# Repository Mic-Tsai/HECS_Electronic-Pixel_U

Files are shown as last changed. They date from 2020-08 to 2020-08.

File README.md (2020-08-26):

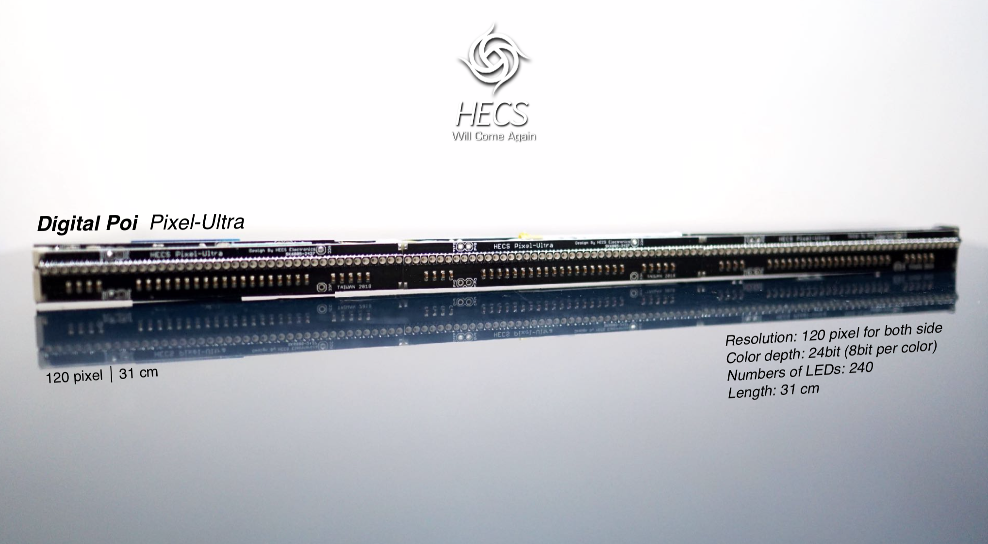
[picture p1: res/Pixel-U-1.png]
*HECS Electronic | Pixel-U*


## HECS Electronic | Pixel-U
### Light Painting Equipment



2013 | HECS

We are a visual team of POI arty performers. Design and develop the light-painting equipment which contains picture & dynamic presentation. This was my college side project during 2013-2014 in KUAS (National Kaohsiung University of Applied Sciences, Taiwan).

- [Promotional Video](https://youtu.be/c2NhDoxItCM)

2017 | Pixel-X

  Re-engineering hardware part, split the core as controller and display, purpose to minimum PCB after-assemble space. LEDs used the improved version SK6812B-3535 (package) from WS2812B-5050, got better heat radiating, the smaller dots will increase the image resolution.

**2018 | Pixel-U**

  **Base on Pixel-X prototype used the same controller board, rebuild the display layout up to 40 LEDs which is smaller package (SK6812B-2427). System compare detail please refer the following slide.**

```
Arduino tool kit, and require the following material:
- MCU: ATmega328p
- Storage: SD card
- Display: SK6812B-2427
- Power source: Li-Po Battery
```

##

### **About Mic**

Director of HECS, design light painting product that contains hardware layout and software programming.

- [Resume](https://drive.google.com/file/d/1NEWwNo3X4ogJMNzp6jpFyT0a6GPGhs7Q/view)

## 

### **About HECS**

Interesting how it works please refer for detail:

- [HECS ISSUU](https://issuu.com/56905554/docs/hecs_book)

- [HECS ISSUU moble device](https://issuu.com/56905554/docs/hecs-book_issuu)

- [HECS Electronics](https://drive.google.com/file/d/1tgr780FQ_Ib0JO3FdQn_M6LVbDeVmUmG/view?usp=sharing)

## 

### **About Hardware**

If you want to buy this board and are in Taiwan, please visit my shop: 

Will OPEN SOON:
* [HECS SHOP](https://www.)
* Contact me via mail (xbcke12345@gmail.com)
* If this project helping. Please generously support =)

   

## 
*HECS Electronic | Pixel-U*
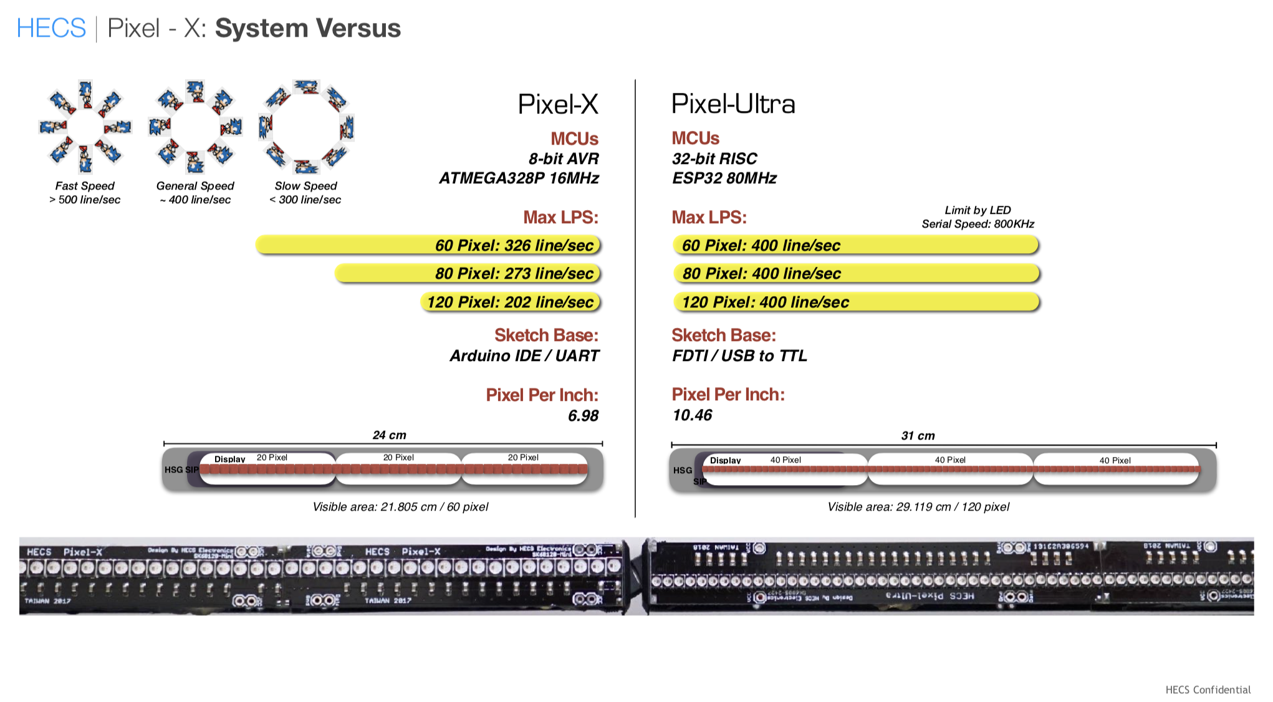
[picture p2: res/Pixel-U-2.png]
*HECS Electronic | Pixel-U*

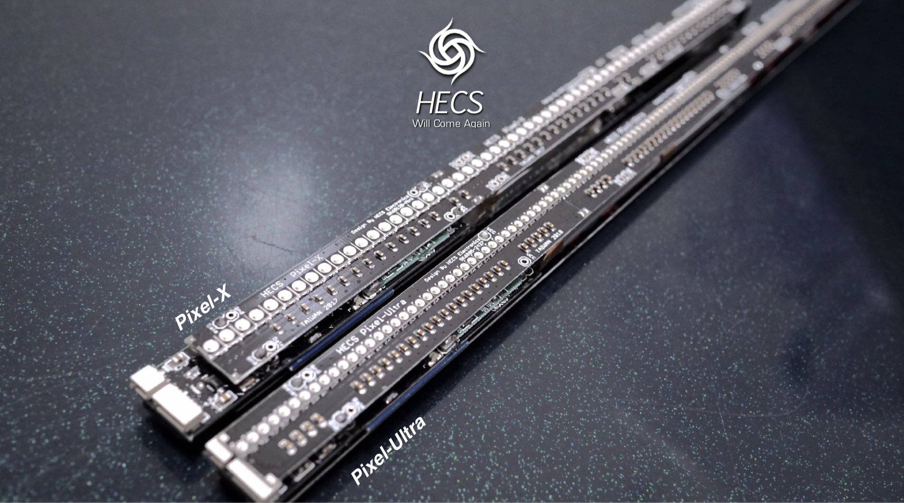
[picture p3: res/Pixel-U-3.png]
*HECS Electronic | Pixel-U*

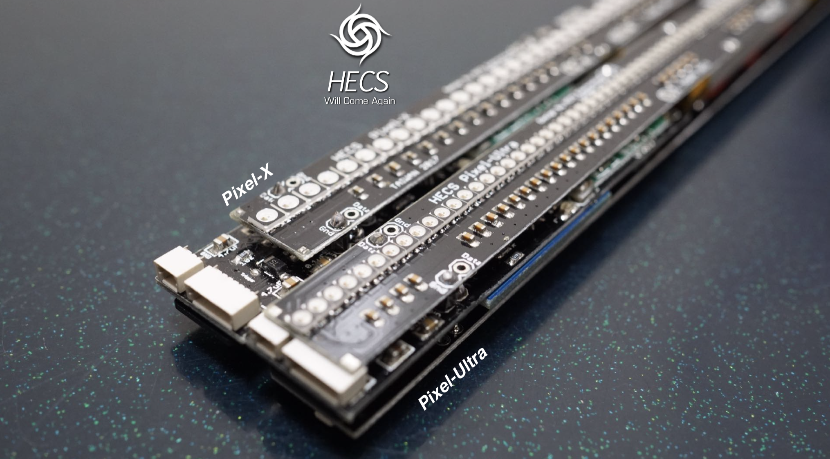
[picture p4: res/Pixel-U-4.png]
*HECS Electronic | Pixel-U*

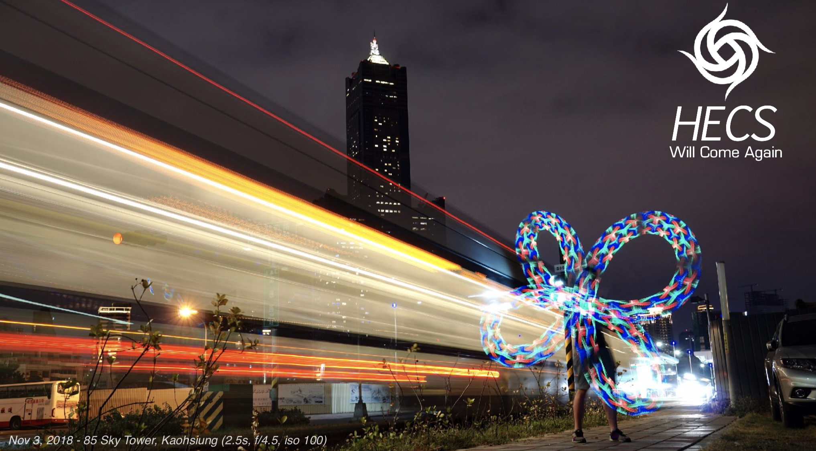
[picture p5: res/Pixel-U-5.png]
*HECS Electronic | Pixel-U*

*HECS Electronic | Pixel-U*
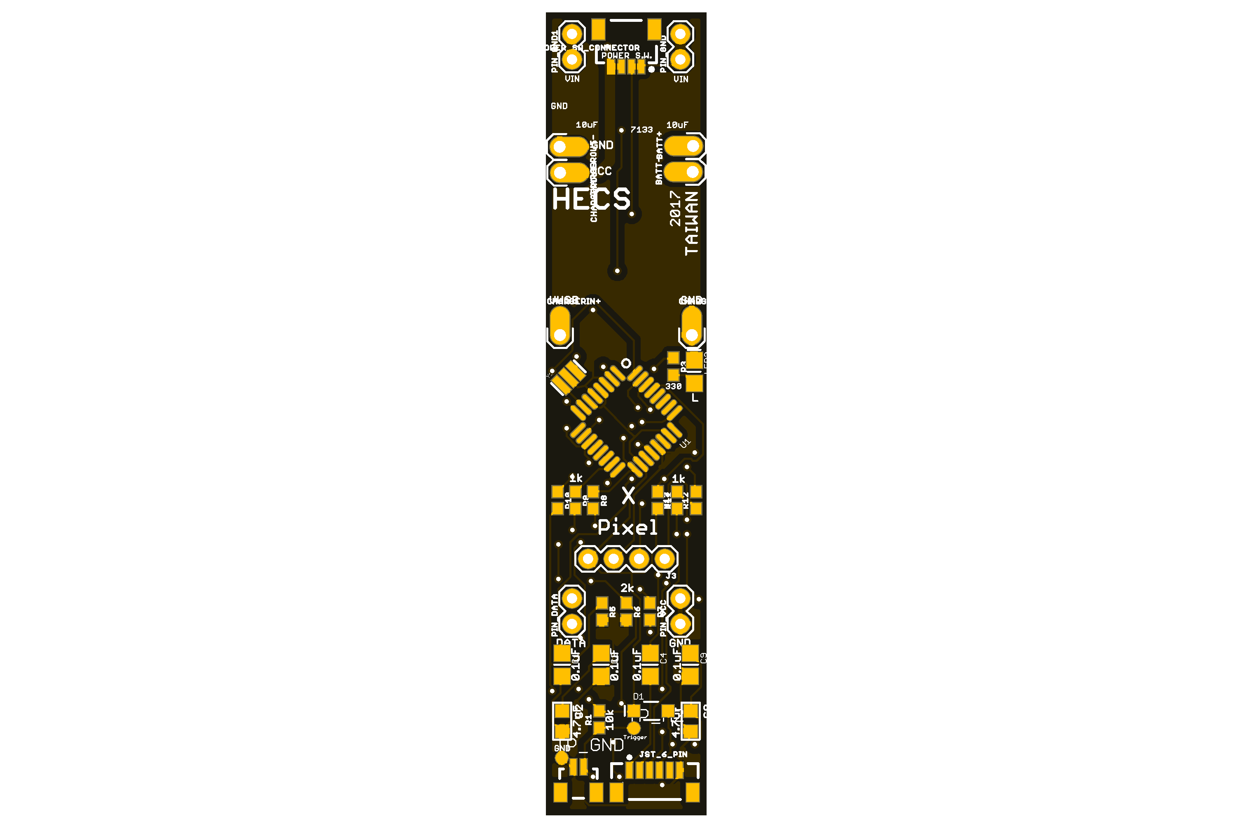
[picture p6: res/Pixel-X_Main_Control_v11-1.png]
*HECS Electronic | Pixel-U*

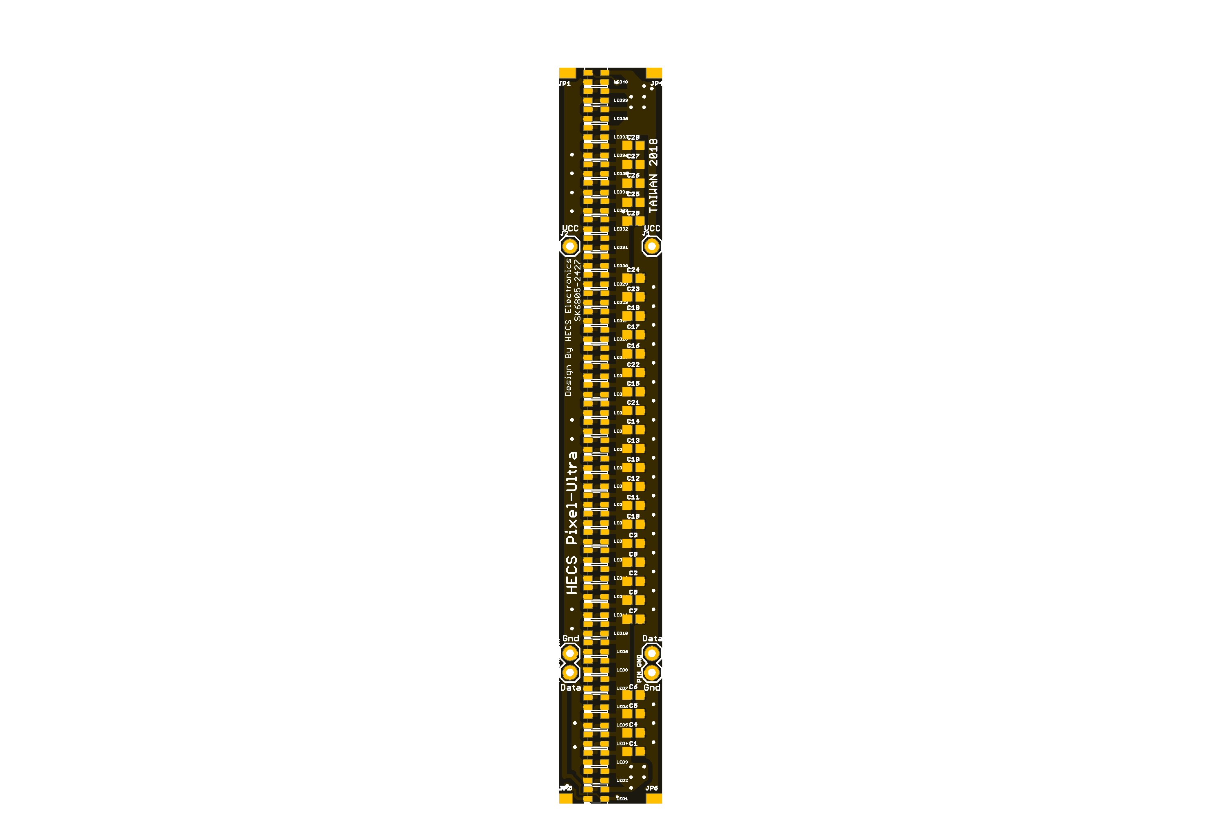
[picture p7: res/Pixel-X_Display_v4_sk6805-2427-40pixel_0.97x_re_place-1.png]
*HECS Electronic | Pixel-U*

## 

>### License Information
>>This product is open source! Both, our hardware and software are open source and licensed under the following:
>>#### Hardware
>>>All hardware is released under [Creative Commons Share-alike 4.0 International](http://creativecommons.org/licenses/by-sa/4.0/)
>>#### Software 
>>>All software is released under the MIT License [http://opensource.org/licenses/MIT](http://opensource.org/licenses/MIT)
>>#### Documentation
>>>The documentation on this page is released under [Creative Commons Share-alike 4.0 International](http://creativecommons.org/licenses/by-sa/4.0/)

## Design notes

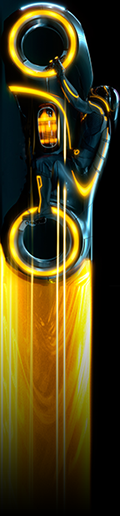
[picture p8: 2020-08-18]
Pixel-U_Image/Pixel-120/frame008.bmp

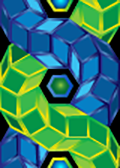
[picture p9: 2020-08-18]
Pixel-U_Image/Pixel-120/frame003.bmp

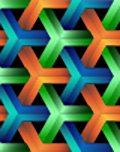
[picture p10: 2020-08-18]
Pixel-U_Image/Pixel-120/frame004.bmp

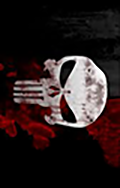
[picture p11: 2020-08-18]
Pixel-U_Image/Pixel-120/frame009.bmp

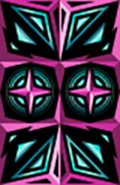
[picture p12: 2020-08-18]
Pixel-U_Image/Pixel-120/frame002.bmp

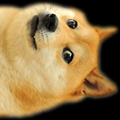
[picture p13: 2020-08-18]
Pixel-U_Image/Pixel-120/frame006.bmp

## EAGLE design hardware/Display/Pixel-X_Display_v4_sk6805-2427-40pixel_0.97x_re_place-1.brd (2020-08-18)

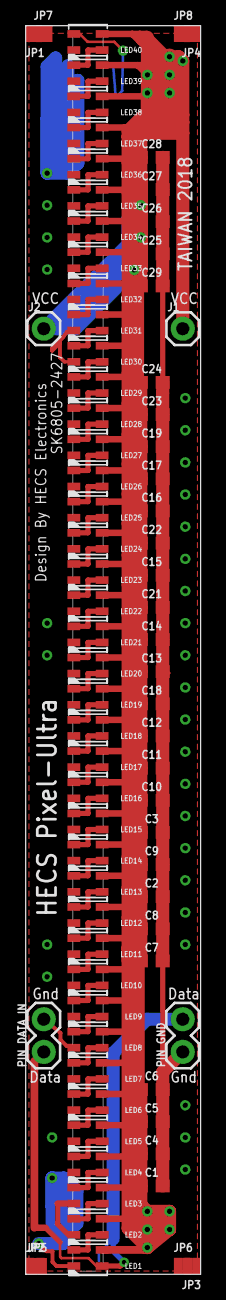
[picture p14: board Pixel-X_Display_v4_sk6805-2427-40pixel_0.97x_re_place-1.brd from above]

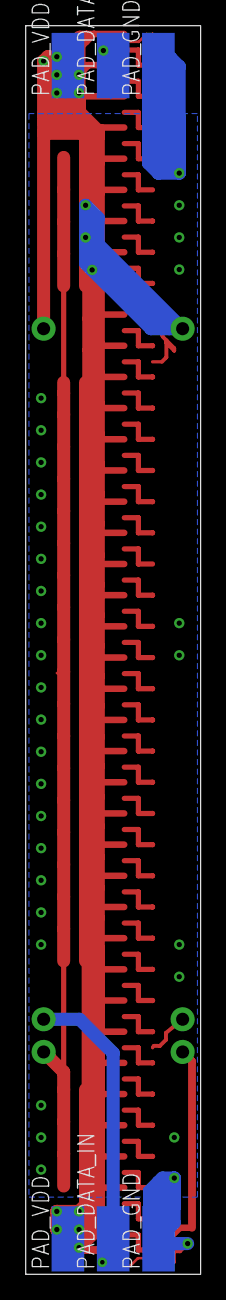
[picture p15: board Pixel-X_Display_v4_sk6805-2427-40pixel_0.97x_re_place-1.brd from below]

Board: 2 copper layers, 13.6 x 97.1 mm, 86 parts (6 on the bottom side), 43 nets.

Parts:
C1, C2, C3, C4, C5, C6, C7, C8, C9, C10, C11, C12, C13, C14, C15, C16, C17, C18, C19, C21, C22, C23, C24, C25, C26, C27, C28, C29: 0.1uF; 0603
J1, J2: 1X01
JP1, JP2, JP3, JP4, JP5, JP6, JP7, JP8: JUMPER-SMT_2_NO_NO-SILK; SMT-JUMPER_2_NO_NO-SILK
LED1, LED2, LED3, LED4, LED5, LED6, LED7, LED8, LED9, LED10, LED11, LED12, LED13, LED14, LED15, LED16, LED17, LED18, LED19, LED20, LED21, LED22, LED23, LED24, LED25, LED26, LED27, LED28, LED29, LED30, LED31, LED32, LED33, LED34, LED35, LED36, LED37, LED38, LED39, LED40: WS2812BSK68052427; LED3535
PAD_DATA_IN: SMD2,54-5,08
PAD_DATA_OUT: SMD2,54-5,08
PAD_GND, PAD_GND1: SMD2,54-5,08
PAD_VDD, PAD_VDD1: SMD2,54-5,08
PIN_DATA_IN: 1X02
PIN_GND: 1X02

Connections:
+5V: C1.1, C2.1, C3.1, C4.1, C5.1, C6.1, C7.1, C8.1, C9.1, C10.1, C11.1, C12.1, C13.1, C14.1, C15.1, C16.1, C17.1, C18.1, C19.1, C21.1, C22.1, C23.1, C24.1, C25.1, C26.1, C27.1, C28.1, C29.1, J1.1, J2.1, LED1.2, LED2.2, LED3.2, LED4.2, LED5.2, LED6.2, LED7.2, LED8.2, LED9.2, LED10.2, LED11.2, LED12.2, LED13.2, LED14.2, LED15.2, LED16.2, LED17.2, LED18.2, LED19.2, LED20.2, LED21.2, LED22.2, LED23.2, LED24.2, LED25.2, LED26.2, LED27.2, LED28.2, LED29.2, LED30.2, LED31.2, LED32.2, LED33.2, LED34.2, LED35.2, LED36.2, LED37.2, LED38.2, LED39.2, LED40.2, PAD_VDD.1, PAD_VDD1.1
COM: C1.2, C2.2, C3.2, C4.2, C5.2, C6.2, C7.2, C8.2, C9.2, C10.2, C11.2, C12.2, C13.2, C14.2, C15.2, C16.2, C17.2, C18.2, C19.2, C21.2, C22.2, C23.2, C24.2, C25.2, C26.2, C27.2, C28.2, C29.2, LED1.4, LED2.4, LED3.4, LED4.4, LED5.4, LED6.4, LED7.4, LED8.4, LED9.4, LED10.4, LED11.4, LED12.4, LED13.4, LED14.4, LED15.4, LED16.4, LED17.4, LED18.4, LED19.4, LED20.4, LED21.4, LED22.4, LED23.4, LED24.4, LED25.4, LED26.4, LED27.4, LED28.4, LED29.4, LED30.4, LED31.4, LED32.4, LED33.4, LED34.4, LED35.4, LED36.4, LED37.4, LED38.4, LED39.4, LED40.4, PAD_GND.1, PAD_GND1.1, PIN_DATA_IN.2, PIN_GND.1
unnamed: LED1.1, PAD_DATA_IN.1, PIN_DATA_IN.1, PIN_GND.2
unnamed: LED1.3, LED2.1
unnamed: LED2.3, LED3.1
unnamed: LED3.3, LED4.1
unnamed: LED4.3, LED5.1
unnamed: LED5.3, LED6.1
unnamed: LED29.3, LED30.1
unnamed: LED6.3, LED7.1
unnamed: LED7.3, LED8.1
unnamed: LED8.3, LED9.1
unnamed: LED9.3, LED10.1
unnamed: LED10.3, LED11.1
unnamed: LED11.3, LED12.1
unnamed: LED12.3, LED13.1
unnamed: LED13.3, LED14.1
unnamed: LED15.3, LED16.1
unnamed: LED16.3, LED17.1
unnamed: LED17.3, LED18.1
unnamed: LED18.3, LED19.1
unnamed: LED19.3, LED20.1
unnamed: LED14.3, LED15.1
unnamed: LED20.3, LED21.1
unnamed: LED21.3, LED22.1
unnamed: LED22.3, LED23.1
unnamed: LED23.3, LED24.1
unnamed: LED24.3, LED25.1
unnamed: LED25.3, LED26.1
unnamed: LED26.3, LED27.1
unnamed: LED27.3, LED28.1
unnamed: LED28.3, LED29.1
unnamed: LED30.3, LED31.1
unnamed: LED39.3, LED40.1
unnamed: LED38.3, LED39.1
unnamed: LED37.3, LED38.1
unnamed: LED36.3, LED37.1
unnamed: LED35.3, LED36.1
unnamed: LED34.3, LED35.1
unnamed: LED33.3, LED34.1
unnamed: LED32.3, LED33.1
unnamed: LED31.3, LED32.1
unnamed: LED40.3, PAD_DATA_OUT.1

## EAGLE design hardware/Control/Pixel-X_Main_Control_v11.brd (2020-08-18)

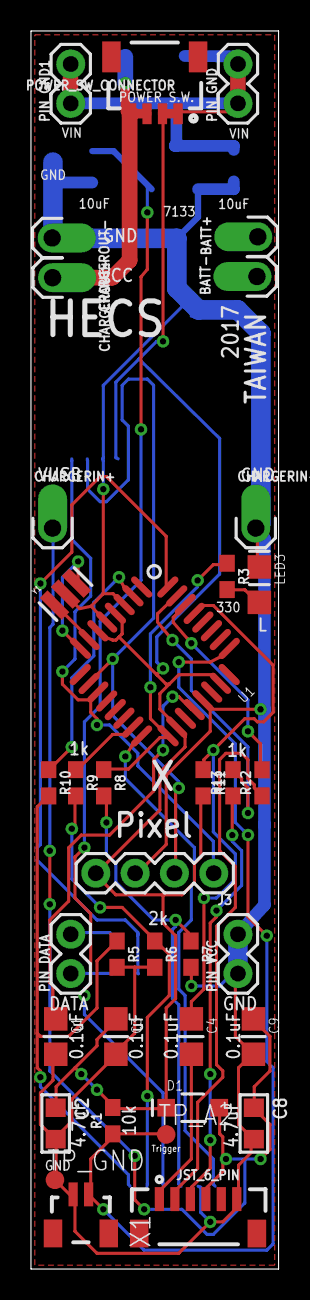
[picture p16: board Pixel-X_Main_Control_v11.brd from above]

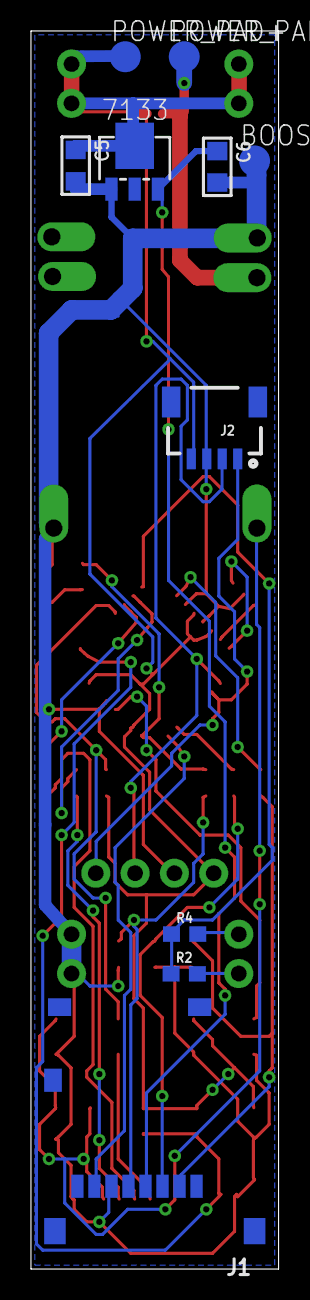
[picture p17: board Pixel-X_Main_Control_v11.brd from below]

Board: 2 copper layers, 16.0 x 80.0 mm, 47 parts (10 on the bottom side), 28 nets.

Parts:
7133: L78LXXCU/BU; SOT89
BATT+: 1X01_OFFSET
BATT-: 1X01_OFFSET
BOOSTOUT-: TPSQTP20R; TP20R
C1, C3, C4, C9: 0.1uF; CAP0805-NP
C2, C8: 4.7uF; C0805
C5, C6: 10uF; C0805
CHARGERIN+: 1X01_OFFSET
CHARGERIN-: 1X01_OFFSET
CHARGEROUT+: 1X01_OFFSET
CHARGEROUT-: 1X01_OFFSET
D1: MBR0520; SOD-123
J1: MICROSD_MOLEX_5025700893; 5025700893
J2: 1X04_1MM_RA
J3: 1X04
JST_6_PIN: JST_6_PIN_VERTICAL; JST-6-SMD-VERT-1.0MM
LED3: L_AMBER; LED0805
PIN_DATA: 1X02
PIN_GND, PIN_GND1: 1X02
PIN_VCC: 1X02
POWER_PAD+: TPSQTP20R; TP20R
POWER_PAD-: TPSQTP20R; TP20R
POWER_SW_CONNECTOR: 1X04_1MM_RA
R1: 10k; 0603
R2, R4: 120; 0603
R3: 330; 0603
R5, R6, R7: 2k; 0603
R8, R9, R10, R11, R12, R13: 1k; 0603
TP_A2: TPTP12R; TP12R
TP_GND: TPTP12R; TP12R
U1: ATMEGA328; QFP032
X1: BM02B-SRSS-TB
Y1: 16MHz; RESONATOR

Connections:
3V3OUT: 7133.3, C6.1, J1.P$4
+5V: 7133.4, C2.1, C3.1, C5.1, D1.1, J2.4, J3.4, PIN_GND.1, PIN_GND.2, PIN_GND1.1, PIN_GND1.2, POWER_PAD+.TP, POWER_SW_CONNECTOR.1, POWER_SW_CONNECTOR.2, R1.2, R11.2, U1.4, U1.6, U1.18, U1.23
A2: R1.1, TP_A2.TP, U1.25, X1.2
AREF: C1.1, U1.20
COM: 7133.1, BOOSTOUT-.TP, C1.2, C2.2, C3.2, C5.2, C6.2, C8.2, C9.2, CHARGERIN-.1, CHARGEROUT-.1, J1.P$6, J2.3, J3.3, JST_6_PIN.6, LED3.1, PIN_VCC.1, PIN_VCC.2, R5.2, R6.2, R7.2, TP_GND.TP, U1.3, U1.5, U1.21, X1.1, Y1.2
D0/RX: R12.2, U1.30
D1/TX: R13.2, U1.31
D2: R2.1, R4.1, U1.32
D4: R10.1, U1.2
D6: J2.2, J3.2, U1.10
D7: J2.1, J3.1, U1.11
D11/MOSI: R9.1, U1.15
D12/MISO: J1.P$7, U1.16
D13/SCK: R3.1, R8.1, U1.17
DTR: C4.1, R11.1, U1.29
unnamed: U1.8, Y1.3
unnamed: U1.7, Y1.1
unnamed: PIN_DATA.2, R4.2
unnamed: PIN_DATA.1, R2.2
unnamed: C4.2, JST_6_PIN.1
unnamed: LED3.2, R3.2
unnamed: J1.P$2, R5.1, R10.2
unnamed: J1.P$3, R6.1, R9.2
unnamed: J1.P$5, R7.1, R8.2
unnamed: CHARGEROUT+.1, POWER_PAD-.TP, POWER_SW_CONNECTOR.3, POWER_SW_CONNECTOR.4
RX: JST_6_PIN.2, R12.1
TX: JST_6_PIN.3, R13.1
VUSB: C8.1, C9.1, CHARGERIN+.1, D1.2, JST_6_PIN.4

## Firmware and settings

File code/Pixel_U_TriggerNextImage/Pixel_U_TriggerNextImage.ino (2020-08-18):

// ###################################################################################
// # Project: Pixel-X v8
// # Engineer:  Mic.Tsai
// # Date:  10 May 2018
// # Objective: Dev.board
// # Usage: ATmega328p
// ###################################################################################

/////////////////////////////////
// Important:
// Only Arduino 1.0.6 can sketch this code
// Check cycle time
/////////////////////////////////

// Requires SdFat library for Arduino:
// http://code.google.com/p/sdfatlib/

// Requires NeoPixel library:
// https://github.com/adafruit/Adafruit_NeoPixel

// This project is base on NeoPixel Painter from Adafruit 
// If you need detail building process please visit here (step by step)
// https://learn.adafruit.com/neopixel-painter?view=all
// https://github.com/adafruit/NeoPixel_Painter
// ###################################################################################

#include <SdFat.h>
#include <avr/pgmspace.h>
#include "./gamma.h"

// CONFIGURABLE STUFF --------------------------------------------------------

#define N_LEDS       120 // Max value is 170 (fits one SD card block)
#define CARD_SELECT   4 // SD card select pin (some shields use #4, not 10)
#define LED_PIN        2 // NeoPixels connect here
#define SPEED         A0 // Speed-setting dial
#define BRIGHTNESS    A0 // Brightness-setting dial
#define TRIGGER       A2 // Playback trigger pin
#define CURRENT_MAX 500 // Max current from power supply (mA)

////1600 for 60 pixel
////3200 for 120 pixel

#define OVERHEAD 150 // Extra microseconds for loop processing, etc.

uint8_t           sdBuf[512],  // One SD block (also for NeoPixel color data)
                  pinMask;     // NeoPixel pin bitmask
uint16_t          maxLPS,      // Max playback lines/sec
                  nFrames = 0, // Total # of image files
                  frame   = 0; // Current image # being painted
uint32_t          firstBlock,  // First block # in temp working file
                  nBlocks;     // Number of blocks in file
Sd2Card           card;        // SD card global instance (only one)
SdVolume          volume;      // Filesystem global instance (only one)
SdFile            root;        // Root directory (only one)
volatile uint8_t *port;        // NeoPixel PORT register

//Forward Declaration: make 1.6.7+ happy
boolean bmpProcess(SdFile &path, char *inName, char *outName, uint8_t *brightness);

// INITIALIZATION ------------------------------------------------------------

void setup() {
  uint8_t  b, startupTrigger, minBrightness;
  char     infile[13], outfile[13];
  boolean  found;
  uint16_t i, n;
  SdFile   tmp;
  uint32_t lastBlock;


  digitalWrite(TRIGGER, HIGH);           // Enable pullup on trigger button
  startupTrigger = digitalRead(TRIGGER); // Poll startup trigger ASAP
  Serial.begin(57600);
  pinMode(LED_PIN, OUTPUT);              // Enable NeoPixel output
  digitalWrite(LED_PIN, LOW);            // Default logic state = low
  port    = portOutputRegister(digitalPinToPort(LED_PIN));
  pinMask = digitalPinToBitMask(LED_PIN);
  memset(sdBuf, 0, N_LEDS * 3);          // Clear LED buffer
  show();                                // Init LEDs to 'off' state
#ifdef ENCODERSTEPS
  digitalWrite(5, HIGH);                 // Enable pullup on encoder pin
#endif

  Serial.print(F("Initializing SD card..."));
  if(!card.init(SPI_FULL_SPEED, CARD_SELECT)) {
    error(F("failed. Things to check:\n"
            "* is a card is inserted?\n"
            "* Is your wiring correct?\n"
            "* did you edit CARD_SELECT to match the SD shield or module?"));
  }
  Serial.println(F("OK"));

  if(!volume.init(&card)) {
    error(F("Could not find FAT16/FAT32 partition.\n"
            "Make sure the card is formatted."));
  }
  root.openRoot(&volume);

  // This simple application always reads the files 'frameNNN.bmp' in
  // the root directory; there's no file selection mechanism or UI.

  // If button is held at startup, the processing step is skipped, just
  // goes right to playback of the prior converted file(s) (if present).
  if(startupTrigger == LOW) { // No button press

    // Two passes are made over the input images.  First pass counts the
    // files and estimates the max brightness level that the power supply
    // can sustain...
    minBrightness = 255;
    do {
      sprintf(infile, "frame%03d.bmp", nFrames);
      b = 255; // Assume frame at full brightness to start...
      // ...it's then modified by the bmpProcess() function here to the
      // actual brightness limit the UBEC can sustain for *this image*.
      if(found = bmpProcess(root, infile, NULL, &b)) {
        nFrames++;
        // Keep track of the minimum 'b' value returned for *all images*.
        // This will later be applied to all, in order that multi-frame
        // animations can have consistent brightness throughout.
        if(b < minBrightness) minBrightness = b;
      }
    } while(found && (nFrames < 1000));

    Serial.print(nFrames);
    Serial.print(" frames\nbrightness = ");
    Serial.println(minBrightness);

    // Read dial, setting brightness between 1 (almost but not quite off)
    // and the previously-estimated safe max.
    minBrightness = map(analogRead(BRIGHTNESS), 0, 1023, 1, minBrightness);
  
    // Second pass now applies brightness adjustment while converting
    // the image(s) from BMP to a raw representation of NeoPixel data
    // (this outputs the file(s) 'frameNNN.tmp' -- any existing file
    // by that name will simply be clobbered, IT DOES NOT ASK).
    for(i=0; i<nFrames; i++) {
      sprintf(infile , "frame%03d.bmp", i);
      sprintf(outfile, "frame%03d.tmp", i);
      b = minBrightness; // Reset b to safe limit on each loop iteration
      bmpProcess(root, infile, outfile, &b);
    }
    //while(digitalRead(TRIGGER) == HIGH); // Wait for button release

  } else { // Button held -- use existing data

    do { // Scan for files to get nFrames
      sprintf(infile, "frame%03d.tmp", nFrames);
      if(found = tmp.open(&root, infile, O_RDONLY)) {
        if(tmp.contiguousRange(&firstBlock, &lastBlock)) {
          nFrames++;
        }
        tmp.close();
      }
    } while(found);

  } // end startupTrigger test

#ifdef ENCODERSTEPS
  // To use a rotary encoder rather than timer, connect one output
  // of encoder to T1 pin (digital pin 5 on Arduino Uno).  A small
  // capacitor across the encoder pins may help for debouncing.
  TCCR1A = _BV(WGM11) | _BV(WGM10);
  TCCR1B = _BV(WGM13) | _BV(WGM12) | _BV(CS12) | _BV(CS11);
#else
  // Prepare for playback from file; make a full read pass through the
  // file to estimate block read time (+5% margin) and max playback
  // lines/sec.  Not all SD cards perform the same.  This makes sure a
  // reasonable speed limit is used.
  for(i=0; i<nFrames; i++) { // Scan all files
    sprintf(infile, "frame%03d.tmp", i);
    tmp.open(&root, infile, O_RDONLY);
    tmp.contiguousRange(&firstBlock, &lastBlock);
    nBlocks = tmp.fileSize() / 512;
    tmp.close();
    n = (uint16_t)(1000000L /                         // 1 uSec /
      (((benchmark(firstBlock, nBlocks) * 21) / 20) + // time + 5% +
       (N_LEDS * 30L) + OVERHEAD));                   // 30 uSec/pixel
    if(n > maxLPS) maxLPS = n;
  }
  if(maxLPS > 400) maxLPS = 400; // NeoPixel PWM rate is ~400 Hz
  Serial.print(F("Max lines/sec: "));
  Serial.println(maxLPS);

  // Set up Timer1 for 64:1 prescale (250 KHz clock source),
  // fast PWM mode, no PWM out.
  TCCR1A = _BV(WGM11) | _BV(WGM10);
  TCCR1B = _BV(WGM13) | _BV(WGM12) | _BV(CS11) | _BV(CS10);
  // Timer1 interrupt is not used; instead, overflow bit is tightly
  // polled.  Very infrequently a block read may inexplicably take longer
  // than normal...using an interrupt, the code would clobber itself.
  // By polling instead, worst case is just a minor glitch where the
  // corresponding row will be a little thicker than normal.
#endif

  // Timer0 interrupt is disabled for smoother playback.
  // This means delay(), millis(), etc. won't work after this.
  TIMSK0 = 0;
}

// Startup error handler; doesn't return, doesn't run loop(), just stops.
static void error(const __FlashStringHelper *ptr) {
    Serial.println(ptr); // Show message
    for(;;);             // and hang
}

// PLAYBACK LOOP -------------------------------------------------------------

void loop() {
  uint32_t block    = 0;     // Current block # within file
  boolean  stopFlag = false; // If set, stop playback loop
  uint32_t lastBlock;
  char     infile[13];
  SdFile   tmp;

  // Get existing contiguous tempfile info
  sprintf(infile, "frame%03d.tmp", frame);
  if(!tmp.open(&root, infile, O_RDONLY)) {
    error(F("Could not open NeoPixel tempfile for input"));
  }
  if(!tmp.contiguousRange(&firstBlock, &lastBlock)) {
    error(F("NeoPixel tempfile is not contiguous"));
  }
  // Number of blocks needs to be calculated from file size, not the
  // range values.  The contiguous file creation and range functions
  // work on cluster boundaries, not necessarily the actual file size.
  nBlocks = tmp.fileSize() / 512;

  tmp.close(); // File handle is no longer accessed, just block reads

  // Stage first block, but don't display yet -- the loop below
  // does that only when Timer1 overflows.
  card.readBlock(firstBlock, sdBuf);
  // readBlock is used rather than readStart/readData/readEnd as
  // the duration between block reads may exceed the SD timeout.

  while(digitalRead(TRIGGER) == LOW);   // Wait for trigger button

#ifdef ENCODERSTEPS
  // Set up for rotary encoder
  TCNT1 = 0;
  OCR1A = ENCODERSTEPS;
#else
  // Set up timer based on dial input
  uint32_t linesPerSec = map(analogRead(SPEED), 0, 1023, 10, maxLPS);
  // Serial.println(linesPerSec);
  OCR1A = (F_CPU / 64) / linesPerSec;          // Timer1 interval
#endif

  for(;;) {
    while(!(TIFR1 & _BV(TOV1)));               // Wait for Timer1 overflow
    TIFR1 |= _BV(TOV1);                        // Clear overflow bit

    show();                                    // Display current line
    if(stopFlag) break;                        // Break when done

    if(++block >= nBlocks) {                   // Past last block?
      if(digitalRead(TRIGGER) == LOW) {       // Trigger released?
        memset(sdBuf, 0, N_LEDS * 3);          // LEDs off on next pass
        stopFlag = true;                       // Stop playback on next pass
        continue;
      }                                        // Else trigger still held
      block = 0;                               // Loop back to start
    }
    card.readBlock(block + firstBlock, sdBuf); // Load next pixel row
  }

  if(++frame >= nFrames) frame = 0;
}

// BMP->NEOPIXEL FILE CONVERSION ---------------------------------------------

#define BMP_BLUE  0 // BMP and NeoPixels have R/G/B color
#define BMP_GREEN 1 // components in different orders.
#define BMP_RED   2 // (BMP = BGR, Neo = GRB)
#define NEO_GREEN 0
#define NEO_RED   1
#define NEO_BLUE  2

// Convert file from 24-bit Windows BMP format to raw NeoPixel datastream.
// Conversion is bottom-to-top (see notes below)...for horizontal light
// painting, the image is NOT rotated here (the per-pixel file seeking this
// requires takes FOREVER on the Arduino).  Instead, such images should be
// rotated counterclockwise (in Photoshop or other editor) prior to moving
// to SD card.  As currently written, both the input and output files need
// to be in the same directory.  Brightness is set during conversion; there
// aren't enough cycles to do this in realtime during playback.  To change
// brightness, re-process image file using new brightness value.
boolean bmpProcess(
  SdFile  &path,
  char    *inName,
  char    *outName,
  uint8_t *brightness) {

  SdFile    inFile,              // Windows BMP file for input
            outFile;             // NeoPixel temp file for output
  boolean   ok        = false,   // 'true' on valid BMP & output file
            flip      = false;   // 'true' if image stored top-to-bottom
  int       bmpWidth,            // BMP width in pixels
            bmpHeight,           // BMP height in pixels
            bmpStartCol,         // First BMP column to process (crop/center)
            columns,             // Number of columns to process (crop/center)
            row,                 // Current image row (Y)
            column;              // and column (X)
  uint8_t  *ditherRow,           // 16-element dither array for current row
            pixel[3],            // For reordering color data, BGR to GRB
            b = 0,               // 1 + *brightness
            d,                   // Dither value for row/column
            color,               // Color component index (R/G/B)
            raw,                 // 'Raw' R/G/B color value
            corr,                // Gamma-corrected R/G/B
           *ledPtr,              // Pointer into sdBuf (output)
           *ledStartPtr;         // First LED column to process (crop/center)
  uint16_t  b16;                 // 16-bit dup of b
  uint32_t  bmpImageoffset,      // Start of image data in BMP file
            lineMax   = 0L,      // Cumulative brightness of brightest line
            rowSize,             // BMP row size (bytes) w/32-bit alignment
            sum,                 // Sum of pixels in row
            startTime = millis();

  if(brightness)           b = 1 + *brightness; // Wraps around, fun with maths
  else if(NULL == outName) return false; // MUST pass brightness for power est.

  Serial.print(F("Reading file '"));
  Serial.print(inName);
  Serial.print(F("'..."));
  if(!inFile.open(&path, inName, O_RDONLY)) {
    Serial.println(F("error"));
    return false;
  }

  if(inFile.read(sdBuf, 34)             &&    // Load header
    (*(uint16_t *)&sdBuf[ 0] == 0x4D42) &&    // BMP signature
    (*(uint16_t *)&sdBuf[26] == 1)      &&    // Planes: must be 1
    (*(uint16_t *)&sdBuf[28] == 24)     &&    // Bits per pixel: must be 24
    (*(uint32_t *)&sdBuf[30] == 0)) {         // Compression: must be 0 (none)
    // Supported BMP format -- proceed!
    bmpImageoffset = *(uint32_t *)&sdBuf[10]; // Start of image data
    bmpWidth       = *(uint32_t *)&sdBuf[18]; // Image dimensions
    bmpHeight      = *(uint32_t *)&sdBuf[22];
    // That's some nonportable, endian-dependent code right there.

    Serial.print(bmpWidth);
    Serial.write('x');
    Serial.print(bmpHeight);
    Serial.println(F(" pixels"));

    if(outName) { // Doing conversion?  Need outFile.
      // Delete existing outFile file (if any)
      (void)SdFile::remove(&path, outName);
      Serial.print(F("Creating contiguous file..."));
      // NeoPixel working file is always 512 bytes (one SD block) per row
      if(outFile.createContiguous(&path, outName, 512L * bmpHeight)) {
        uint32_t lastBlock;
        outFile.contiguousRange(&firstBlock, &lastBlock);
        // Once we have the first block index, the file handle
        // is no longer needed -- raw block writes are used.
        outFile.close();
        nBlocks = bmpHeight; // See note in setup() re: block calcs
        ok      = true;      // outFile is good; proceed
        Serial.println(F("OK"));
      } else {
        Serial.println(F("error"));
      }
    } else ok = true; // outFile not needed; proceed

    if(ok) { // Valid BMP and contig file (if needed) are ready
      Serial.print(F("Processing..."));

      rowSize = ((bmpWidth * 3) + 3) & ~3; // 32-bit line boundary
      b16     = (int)b;

      if(bmpHeight < 0) {       // If bmpHeight is negative,
        bmpHeight = -bmpHeight; // image is in top-down order.
        flip      = true;       // Rare, but happens.
      }

      if(bmpWidth >= N_LEDS) { // BMP matches LED bar width, or crop image
        bmpStartCol = (bmpWidth - N_LEDS) / 2;
        ledStartPtr = sdBuf;
        columns     = N_LEDS;
      } else {                 // Center narrow image within LED bar
        bmpStartCol = 0;
        ledStartPtr = &sdBuf[((N_LEDS - bmpWidth) / 2) * 3];
        columns     = bmpWidth;
        memset(sdBuf, 0, N_LEDS * 3); // Clear left/right pixels
      }

      for(row=0; row<bmpHeight; row++) { // For each row in image...
        Serial.write('.');
        // Image is converted from bottom to top.  This is on purpose!
        // The ground (physical ground, not the electrical kind) provides
        // a uniform point of reference for multi-frame vertical painting...
        // could then use something like a leaf switch to trigger playback,
        // lifting the light bar like making giant soap bubbles.

        // Seek to first pixel to load for this row...
        inFile.seekSet(
          bmpImageoffset + (bmpStartCol * 3) + (rowSize * (flip ?
          (bmpHeight - 1 - row) : // Image is stored top-to-bottom
          row)));                 // Image stored bottom-to-top
        if(!inFile.read(ledStartPtr, columns * 3))  // Load row
          Serial.println(F("Read error"));

        sum       = 0L;
        ditherRow = (uint8_t *)&dither[row & 0x0F]; // Dither values for row
        ledPtr    = ledStartPtr;
        for(column=0; column<columns; column++) {   // For each column...
          if(b) { // Scale brightness, reorder R/G/B
            pixel[NEO_BLUE]  = (ledPtr[BMP_BLUE]  * b16) >> 8;
            pixel[NEO_GREEN] = (ledPtr[BMP_GREEN] * b16) >> 8;
            pixel[NEO_RED]   = (ledPtr[BMP_RED]   * b16) >> 8;
          } else { // Full brightness, reorder R/G/B
            pixel[NEO_BLUE]  = ledPtr[BMP_BLUE];
            pixel[NEO_GREEN] = ledPtr[BMP_GREEN];
            pixel[NEO_RED]   = ledPtr[BMP_RED];
          }

          d = pgm_read_byte(&ditherRow[column & 0x0F]); // Dither probability
          for(color=0; color<3; color++) {              // 3 color bytes...
            raw  = pixel[color];                        // 'Raw' G/R/B
            corr = pgm_read_byte(&gamma[raw]);          // Gamma-corrected
            if(pgm_read_byte(&bump[raw]) > d) corr++;   // Dither up?
            *ledPtr++ = corr;                           // Store back in sdBuf
            sum      += corr;                           // Total brightness
          } // Next color byte
        } // Next column

        if(outName) {
          if(!card.writeBlock(firstBlock + row, (uint8_t *)sdBuf))
            Serial.println(F("Write error"));
        }
        if(sum > lineMax) lineMax = sum;

      } // Next row
      Serial.println(F("OK"));

      if(brightness) {
        lineMax = (lineMax * 20) / 255; // Est current @ ~20 mA/LED
        if(lineMax > CURRENT_MAX) {
          // Estimate suitable brightness based on CURRENT_MAX
          *brightness = (*brightness * (uint32_t)CURRENT_MAX) / lineMax;
        } // Else no recommended change
      }

      Serial.print(F("Processed in "));
      Serial.print(millis() - startTime);
      Serial.println(F(" ms"));

    } // end 'ok' check
  } else { // end BMP header check
    Serial.println(F("BMP format not recognized."));
  }

  inFile.close();
  return ok; // 'false' on various file open/create errors
}

// MISC UTILITY FUNCTIONS ----------------------------------------------------

// Estimate maximum block-read time for card (microseconds)
static uint32_t benchmark(uint32_t block, uint32_t n) {
  uint32_t t, maxTime = 0L;

  do {
    t = micros();
    card.readBlock(block++, sdBuf);
    if((t = (micros() - t)) > maxTime) maxTime = t;
  } while(--n);

  return maxTime;
}

// NEOPIXEL FUNCTIONS --------------------------------------------------------

// The normal NeoPixel library isn't used by this project.  SD I/O and
// NeoPixels need to occupy the same buffer, there isn't quite an elegant
// way to do this with the existing library that avoids refreshing a longer
// strip than necessary.  Instead, just the core update function for 800 KHz
// pixels on 16 MHz AVR is replicated here; not handling every permutation.

static void show(void) {
  volatile uint16_t
    i   = N_LEDS * 3; // Loop counter
  volatile uint8_t
   *ptr = sdBuf,      // Pointer to next byte
    b   = *ptr++,     // Current byte value
    hi,               // PORT w/output bit set high
    lo,               // PORT w/output bit set low
    next,
    bit = 8;

  noInterrupts();
  hi   = *port |  pinMask;
  lo   = *port & ~pinMask;
  next = lo;

  asm volatile(
   "head20_%=:"                "\n\t"
    "st   %a[port],  %[hi]"    "\n\t"
    "sbrc %[byte],  7"         "\n\t"
     "mov  %[next], %[hi]"     "\n\t"
    "dec  %[bit]"              "\n\t"
    "st   %a[port],  %[next]"  "\n\t"
    "mov  %[next] ,  %[lo]"    "\n\t"
    "breq nextbyte20_%="       "\n\t"
    "rol  %[byte]"             "\n\t"
    "rjmp .+0"                 "\n\t"
    "nop"                      "\n\t"
    "st   %a[port],  %[lo]"    "\n\t"
    "nop"                      "\n\t"
    "rjmp .+0"                 "\n\t"
    "rjmp head20_%="           "\n\t"
   "nextbyte20_%=:"            "\n\t"
    "ldi  %[bit]  ,  8"        "\n\t"
    "ld   %[byte] ,  %a[ptr]+" "\n\t"
    "st   %a[port], %[lo]"     "\n\t"
    "nop"                      "\n\t"
    "sbiw %[count], 1"         "\n\t"
     "brne head20_%="          "\n"
    : [port]  "+e" (port),
      [byte]  "+r" (b),
      [bit]   "+r" (bit),
      [next]  "+r" (next),
      [count] "+w" (i)
    : [ptr]    "e" (ptr),
      [hi]     "r" (hi),
      [lo]     "r" (lo));

  interrupts();
  // There's no explicit 50 uS delay here as with most NeoPixel code;
  // SD card block read provides ample time for latch!
}



// ADAFRUIT NEOPIXEL LIGHT PAINTER SKETCH: Reads 24-bit BMP image from
// SD card, plays back on NeoPixel strip for long-exposure photography.

// Requires SdFat library for Arduino:
// http://code.google.com/p/sdfatlib/
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

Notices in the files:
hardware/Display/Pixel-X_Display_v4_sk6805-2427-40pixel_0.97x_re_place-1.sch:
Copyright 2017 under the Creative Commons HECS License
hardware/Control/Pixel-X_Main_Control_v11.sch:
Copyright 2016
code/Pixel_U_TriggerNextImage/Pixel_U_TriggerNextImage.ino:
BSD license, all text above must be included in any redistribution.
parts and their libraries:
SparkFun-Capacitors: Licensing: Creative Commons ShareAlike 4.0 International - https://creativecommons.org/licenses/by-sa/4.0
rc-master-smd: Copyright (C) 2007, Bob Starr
